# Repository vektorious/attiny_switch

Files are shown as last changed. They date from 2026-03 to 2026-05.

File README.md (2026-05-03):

# attiny_switch

Repository layout:
- `src/`: ATtiny1614 firmware (PlatformIO project)
- `pcb/`: KiCad project and gerbers

## Firmware target

- MCU: `ATtiny1614`
- `PA1`: ISP772T `IN` control
- `PA0`: dedicated `UPDI/RESET` pin, reserved for programming/debug and **not** used for switch control

Current behavior:
- On reset, drive `PA1` low immediately
- Then loop forever: OFF 50 min, ON 10 min
- MCU sleeps in `STANDBY` and wakes from RTC once per minute

## PlatformIO

`platformio.ini` is configured for bare-metal register-level C (no Arduino framework).

Build:

```powershell
pio run
```

Upload over UPDI (PA0):

1. Set your serial port in `platformio.ini` (`upload_port = COMx`).
2. Run:

```powershell
pio run -t upload
```

The configured upload command uses `avrdude` with `serialupdi`.

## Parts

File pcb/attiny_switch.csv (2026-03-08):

# | Reference | Qty | Value | Footprint | DNP
1 | BT1 | 1 | Battery_Cell | Eagle-12BH212P-GR:Untitled
2 | C1, C2 | 2 | 100nF | Capacitor_SMD:C_1206_3216Metric
3 | C3 | 1 | 10uF | Capacitor_SMD:C_1206_3216Metric
4 | D1 | 1 | LED | LED_SMD:LED_1206_3216Metric
5 | J1 | 1 | 12V in | TerminalBlock:TerminalBlock_MaiXu_MX126-5.0-02P_1x02_P5.00mm
6 | J2 | 1 | 12V out | TerminalBlock:TerminalBlock_MaiXu_MX126-5.0-02P_1x02_P5.00mm
7 | J3 | 1 | UPDI Connector | Connector_PinHeader_2.54mm:PinHeader_1x03_P2.54mm_Vertical
8 | J4 | 1 | RPI Signal (OK) | TerminalBlock:TerminalBlock_MaiXu_MX126-5.0-02P_1x02_P5.00mm
9 | J5 | 1 | Serial Connector | Connector_PinHeader_2.54mm:PinHeader_1x04_P2.54mm_Vertical
10 | J6 | 1 | RPI Signal | TerminalBlock:TerminalBlock_MaiXu_MX126-5.0-02P_1x02_P5.00mm
11 | R1 | 1 | 4,7k | Resistor_SMD:R_1206_3216Metric
12 | R2 | 1 | 1k87 | Resistor_SMD:R_1206_3216Metric
13 | R3 | 1 | 100k | Resistor_SMD:R_1206_3216Metric
14 | R5 | 1 | 7,5k | Resistor_SMD:R_1206_3216Metric
15 | SW1 | 1 | SW_DPDT_x2 | Connector_PinHeader_2.54mm:PinHeader_1x03_P2.54mm_Vertical
16 | U1 | 1 | ATtiny1614-SS | Package_SO:SOIC-14_3.9x8.7mm_P1.27mm
17 | U2 | 1 | ISP772T | Package_SO:SOIC-8_3.9x4.9mm_P1.27mm
18 | U3 | 1 | Optocoupler | Package_DIP:DIP-4_W7.62mm

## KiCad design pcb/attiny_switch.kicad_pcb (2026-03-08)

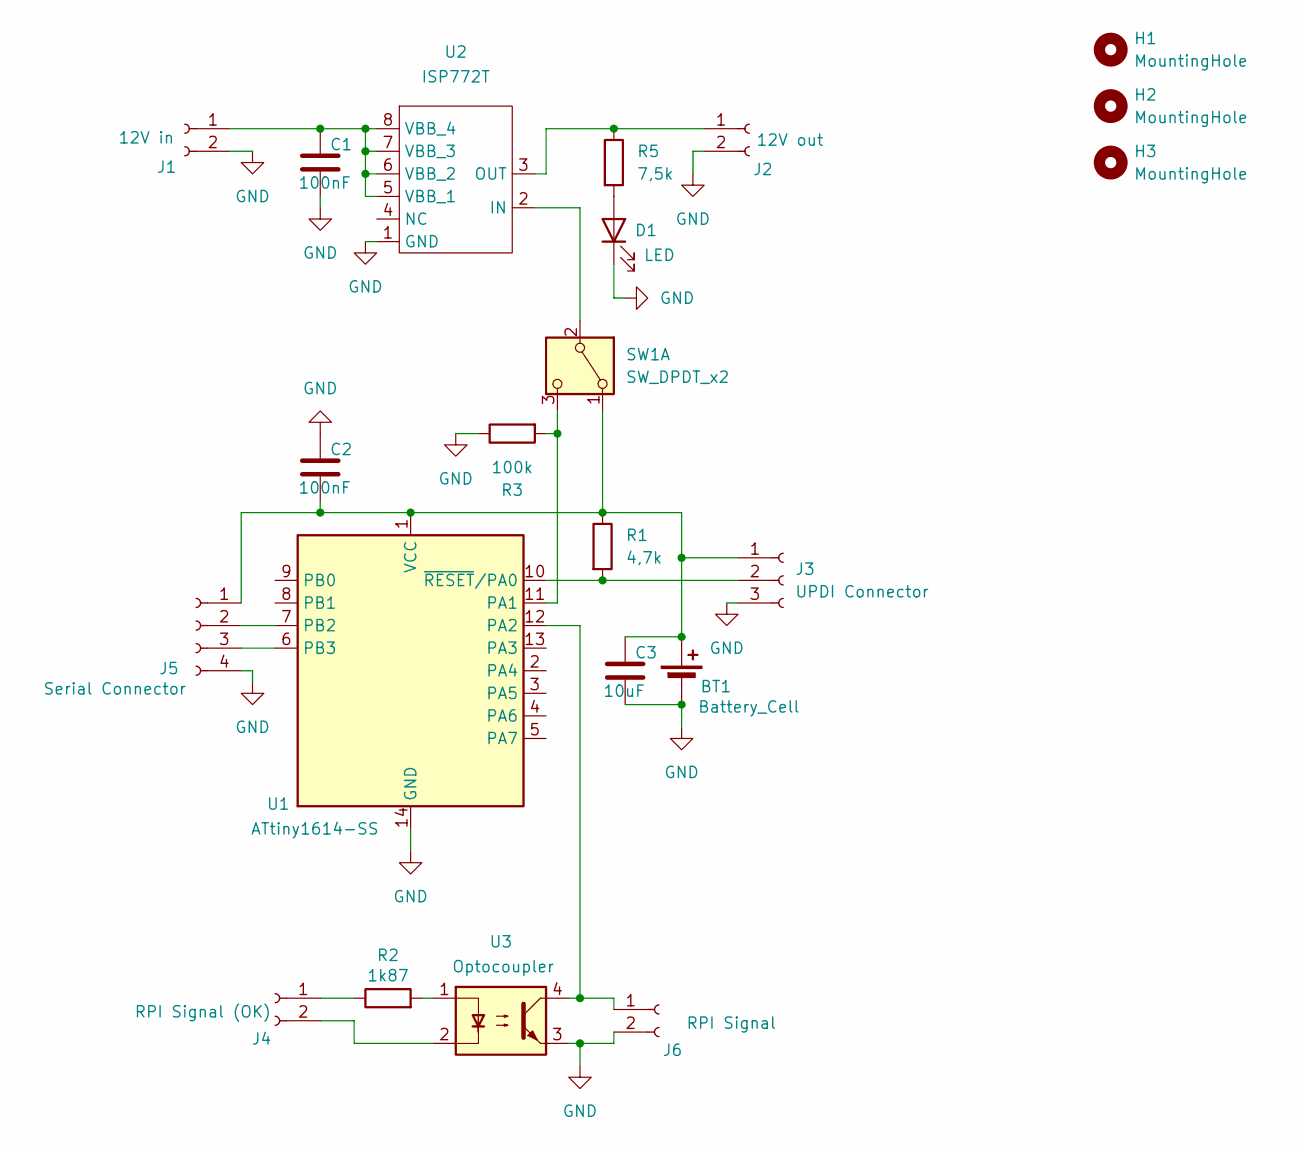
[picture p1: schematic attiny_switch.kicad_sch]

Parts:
BT1: Battery_Cell; Untitled
C1, C2: 100nF; C_1206_3216Metric
C3: 10uF; C_1206_3216Metric
D1: LED; LED_1206_3216Metric
H1, H2, H3: MountingHole; MountingHole_3.2mm_M3
J1: 12V in; TerminalBlock_MaiXu_MX126-5.0-02P_1x02_P5.00mm
J2: 12V out; TerminalBlock_MaiXu_MX126-5.0-02P_1x02_P5.00mm
J3: UPDI Connector; PinHeader_1x03_P2.54mm_Vertical
J4: RPI Signal (OK); TerminalBlock_MaiXu_MX126-5.0-02P_1x02_P5.00mm
J5: Serial Connector; PinHeader_1x04_P2.54mm_Vertical
J6: RPI Signal; TerminalBlock_MaiXu_MX126-5.0-02P_1x02_P5.00mm
R1: 4,7k; R_1206_3216Metric
R2: 1k87; R_1206_3216Metric
R3: 100k; R_1206_3216Metric
R5: 7,5k; R_1206_3216Metric
SW1: SW_DPDT_x2; PinHeader_1x03_P2.54mm_Vertical
U1: ATtiny1614-SS; SOIC-14_3.9x8.7mm_P1.27mm
U2: ISP772T; SOIC-8_3.9x4.9mm_P1.27mm
U3: Optocoupler; DIP-4_W7.62mm

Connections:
GND: BT1.2 (-), C1.2, C2.1, C3.2, D1.1 (K), J1.2, J2.2, J3.3, J5.4, J6.2, R3.1, U1.14 (GND), U2.1 (GND), U3.3
unnamed: BT1.1 (+), C2.2, C3.1, J3.1, J5.1, R1.1, SW1.1 (A), U1.1 (VCC)
unnamed: D1.2 (A), R5.2
unnamed: C1.1, J1.1, U2.5 (VBB_1), U2.6 (VBB_2), U2.7 (VBB_3), U2.8 (VBB_4)
unnamed: J2.1, R5.1, U2.3 (OUT)
unnamed: J3.2, R1.2, U1.10 (~RESET/PA0)
unnamed: J4.1, R2.1
unnamed: J4.2, U3.2
unnamed: J5.2, U1.7 (PB2)
unnamed: J5.3, U1.6 (PB3)
unnamed: J6.1, U1.12 (PA2), U3.4
unnamed: R2.2, U3.1
unnamed: SW1.2 (B), U2.2 (IN)
unnamed: R3.2, SW1.3 (C), U1.11 (PA1)

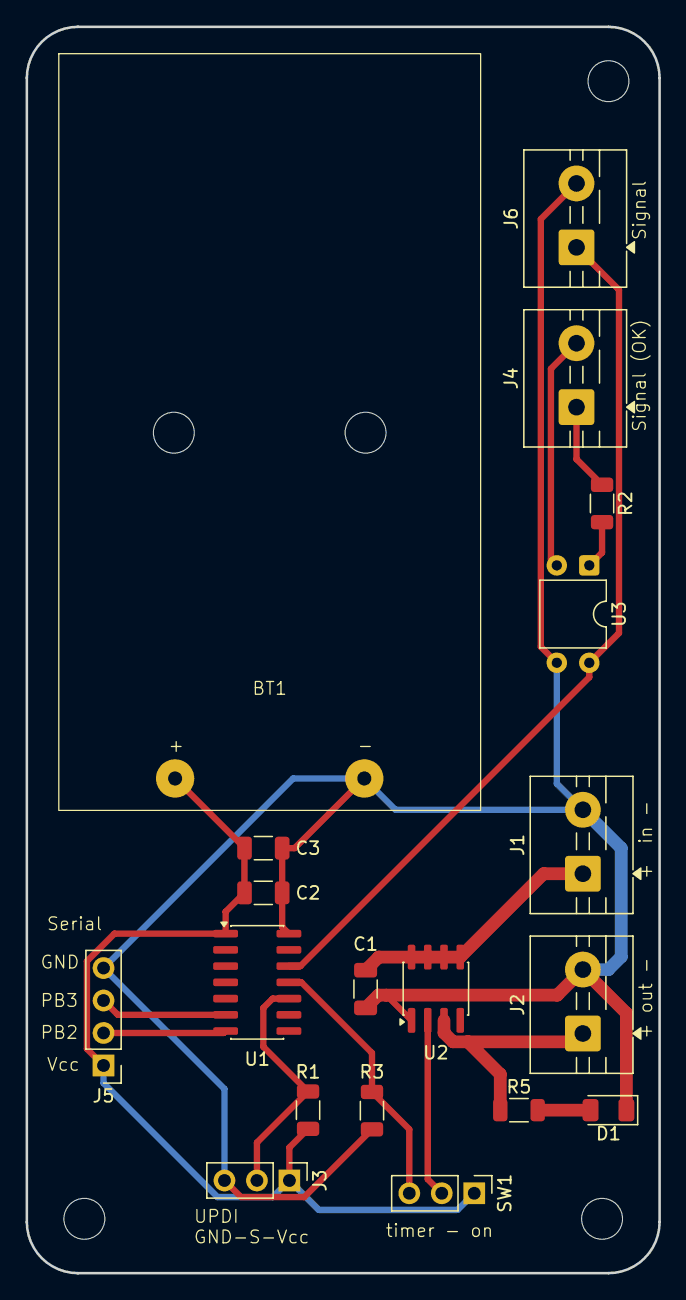
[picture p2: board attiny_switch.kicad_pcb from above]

Board: 2 copper layers, 49.5 x 97.5 mm, 22 parts (0 on the bottom side), 14 nets.

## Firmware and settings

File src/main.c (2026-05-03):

#include <avr/io.h>
#include <avr/interrupt.h>
#include <avr/sleep.h>
#include <stdint.h>

#ifndef F_CPU
// ATtiny1614 ships with internal 20 MHz oscillator and /6 prescaler by default.
#define F_CPU 3333333UL
#endif

#define SWITCH_PIN_bm PIN1_bm  // PA1 -> ISP772T IN

static void gpio_init(void);
static void rtc_minute_wakeup_init(void);
static void switch_on(void);
static void switch_off(void);

volatile uint8_t wake_flag = 0;
static uint8_t minute_counter = 0;

int main(void)
{
    gpio_init();
    switch_off();       // Boot safely with switch OFF.
    minute_counter = 0; // Start a fresh 60-minute cycle after reset.
    rtc_minute_wakeup_init();
    sei();

    for (;;) {
        // Deep sleep mode that keeps RTC running.
        set_sleep_mode(SLEEP_MODE_STANDBY);
        sleep_mode();

        if (wake_flag) {
            wake_flag = 0;
            minute_counter++;

            if (minute_counter == 50U) {
                switch_on();
            } else if (minute_counter == 60U) {
                switch_off();
                minute_counter = 0;
            }
        }
    }
}

static void gpio_init(void)
{
    // Keep PA1 low before enabling output to avoid unintended pulse.
    VPORTA.OUT &= (uint8_t)~SWITCH_PIN_bm;
    VPORTA.DIR |= SWITCH_PIN_bm;

    // Leave PA0 untouched: dedicated UPDI/RESET pin.

    // Put all other GPIOs into a low-power safe state: digital input buffer off.
    PORTA.PIN2CTRL = PORT_ISC_INPUT_DISABLE_gc;
    PORTA.PIN3CTRL = PORT_ISC_INPUT_DISABLE_gc;
    PORTA.PIN4CTRL = PORT_ISC_INPUT_DISABLE_gc;
    PORTA.PIN5CTRL = PORT_ISC_INPUT_DISABLE_gc;
    PORTA.PIN6CTRL = PORT_ISC_INPUT_DISABLE_gc;
    PORTA.PIN7CTRL = PORT_ISC_INPUT_DISABLE_gc;

    PORTB.PIN0CTRL = PORT_ISC_INPUT_DISABLE_gc;
    PORTB.PIN1CTRL = PORT_ISC_INPUT_DISABLE_gc;
    PORTB.PIN2CTRL = PORT_ISC_INPUT_DISABLE_gc;
    PORTB.PIN3CTRL = PORT_ISC_INPUT_DISABLE_gc;
}

static void switch_on(void)
{
    VPORTA.OUT |= SWITCH_PIN_bm;
}

static void switch_off(void)
{
    VPORTA.OUT &= (uint8_t)~SWITCH_PIN_bm;
}

static void rtc_minute_wakeup_init(void)
{
    while (RTC.STATUS > 0) {
        // Wait for RTC sync.
    }

    // 32.768 kHz / 1024 = 32 Hz, overflow every 1920 counts = 60 s.
    RTC.CLKSEL = RTC_CLKSEL_INT32K_gc;
    RTC.PER = 1919U;
    RTC.CNT = 0U;
    RTC.INTCTRL = RTC_OVF_bm;

    RTC.CTRLA = RTC_PRESCALER_DIV1024_gc | RTC_RUNSTDBY_bm | RTC_RTCEN_bm;
}

ISR(RTC_CNT_vect)
{
    RTC.INTFLAGS = RTC_OVF_bm; // Clear overflow interrupt flag.
    wake_flag = 1;
}

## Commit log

2026-03-08 PCB rev1
    [attiny_switch-B_Cu.gbr, attiny_switch-B_Mask.gbr, attiny_switch-B_Paste.gbr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]
2026-03-09 added code
    [attiny_switch-B_Cu.gbr, attiny_switch-B_Mask.gbr, attiny_switch-B_Paste.gbr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]
2026-10-29 Update netlist paths after repo move, drop stale lock file
    Point the BOM/netlist export at the new privat/attiny_switch/pcb location and remove a LibreOffice lock file that was committed by accident.
